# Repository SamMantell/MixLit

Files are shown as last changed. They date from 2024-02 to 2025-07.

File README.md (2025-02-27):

# MixLit - Work in Progress
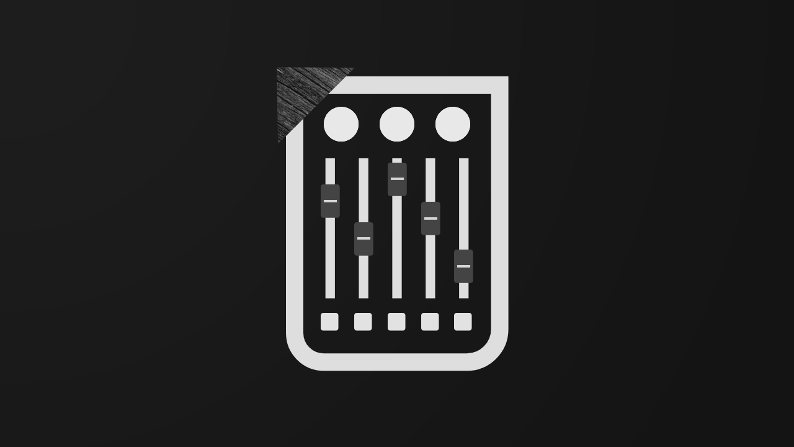
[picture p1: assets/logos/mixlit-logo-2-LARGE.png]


The MixLit is a small sound desk that can control app volumes on a Windows PC. It uses an arduino nano as the controller and talks to our software over USB serial.

The case can be 3D printed and both STEP and STL files are provided

The PCB was designed in KiCAD and we used PCB Way to get them manafactured

Software is a Flutter application.

This repo contains firmware, software and hardware.

# Images
Image of the device:
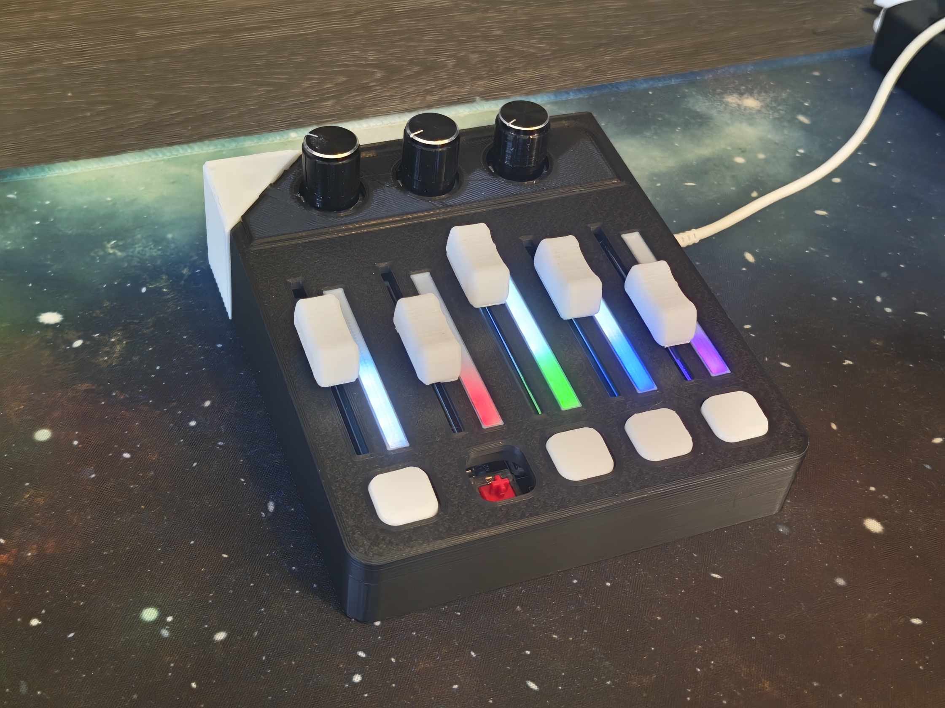
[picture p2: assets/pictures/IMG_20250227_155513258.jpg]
Image of the MixLit

PCB:
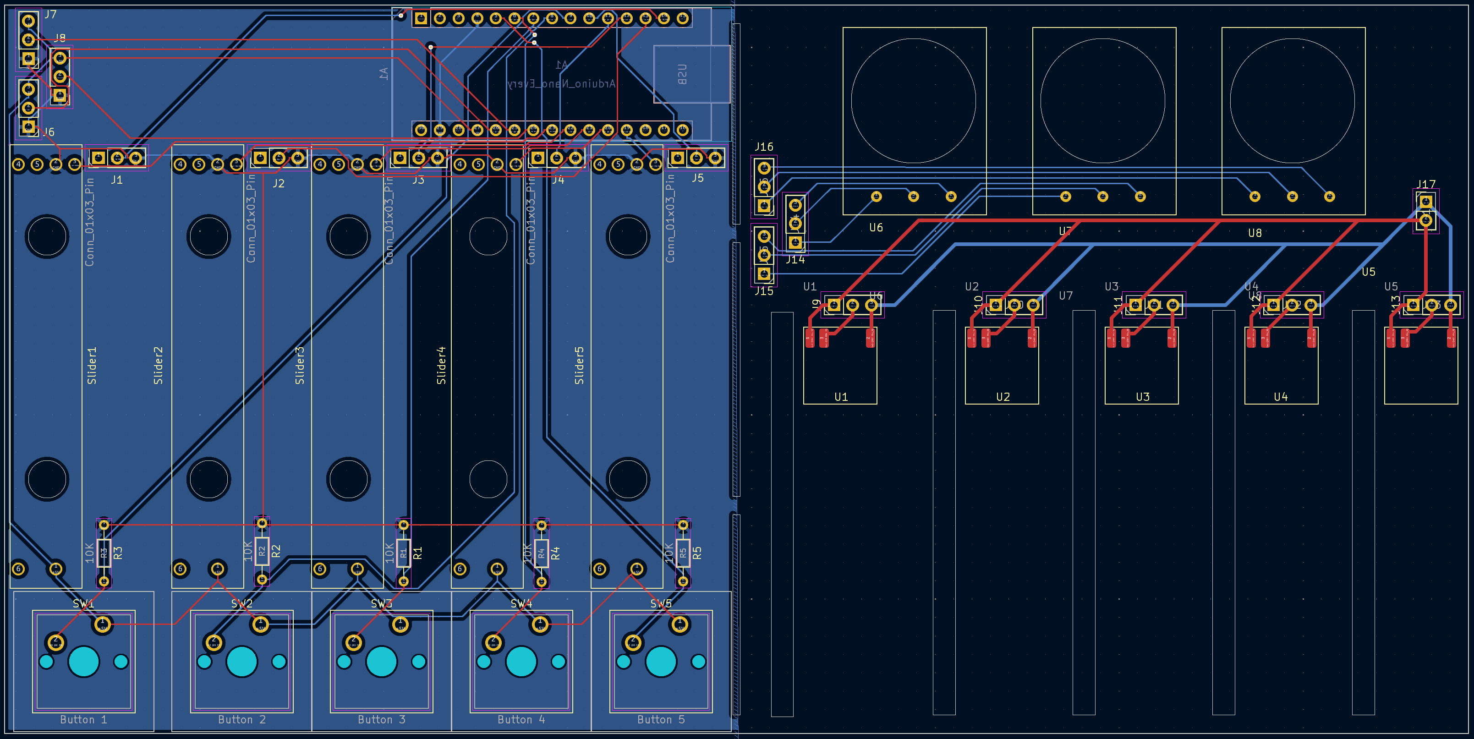
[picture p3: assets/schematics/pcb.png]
Image of the PCB Diagram

Software:
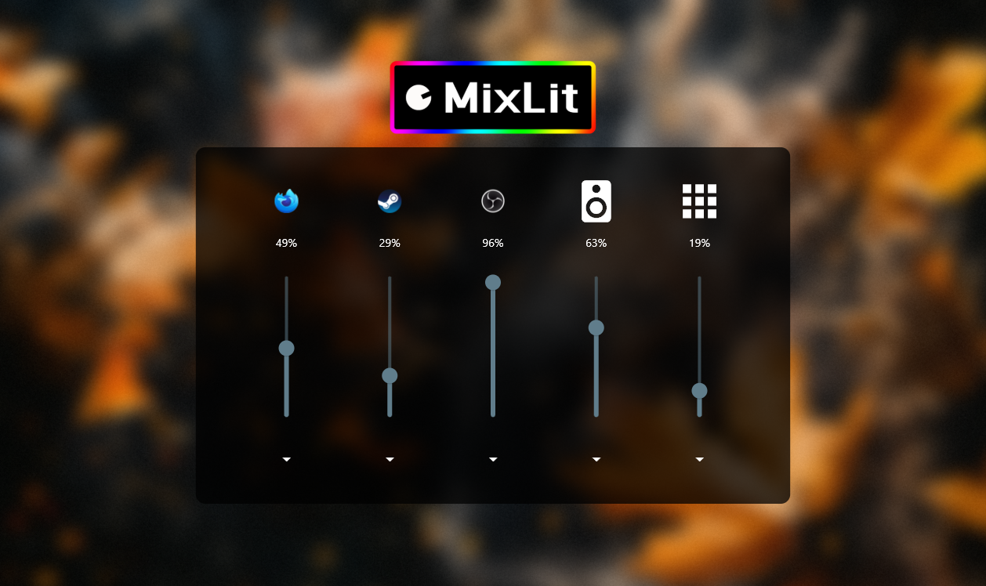
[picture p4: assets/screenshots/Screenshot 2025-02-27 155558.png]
Screenshot of the software


# 📦 Hardware
**» Order the Hardware we used from the links below.**

💡 WS2812B - LIGHTING - https://www.amazon.co.uk/dp/B0CF57NMHN

🎚️ 10K Ohm Slide Potentiometer - https://www.amazon.co.uk/dp/B07PNDLKQQ?psc=1

🎛️ 10K Ohm Rotation Potentiometer - https://www.amazon.co.uk/dp/B07B64MWRF?psc=1

🎮 Arduino Nano - https://www.amazon.co.uk/dp/B0CJHMZZWS

#

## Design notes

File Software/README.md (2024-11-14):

# mixlit

A new Flutter project.

## Getting Started

This project is a starting point for a Flutter application.

A few resources to get you started if this is your first Flutter project:

- [Lab: Write your first Flutter app](https://docs.flutter.dev/get-started/codelab)
- [Cookbook: Useful Flutter samples](https://docs.flutter.dev/cookbook)

For help getting started with Flutter development, view the
[online documentation](https://docs.flutter.dev/), which offers tutorials,
samples, guidance on mobile development, and a full API reference.

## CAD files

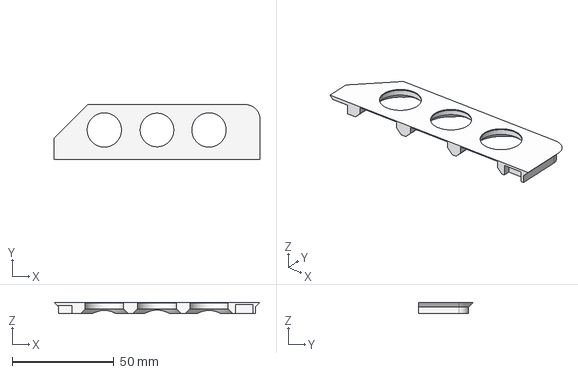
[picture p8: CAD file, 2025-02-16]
Hardware/Case/V2/STEP/Full PCB - Spin Dial Cover.step
101.3 x 26.9 x 5.50 mm

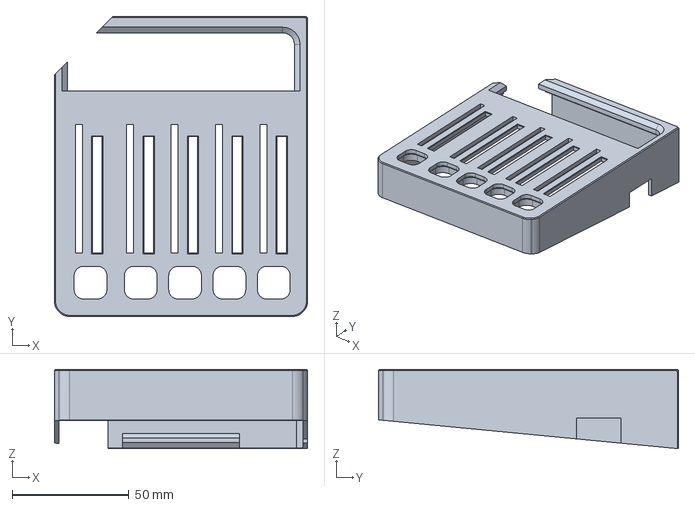
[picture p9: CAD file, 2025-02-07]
Hardware/Case/V2/STEP/Case - Case Main.step
108.5 x 128.5 x 34.0 mm

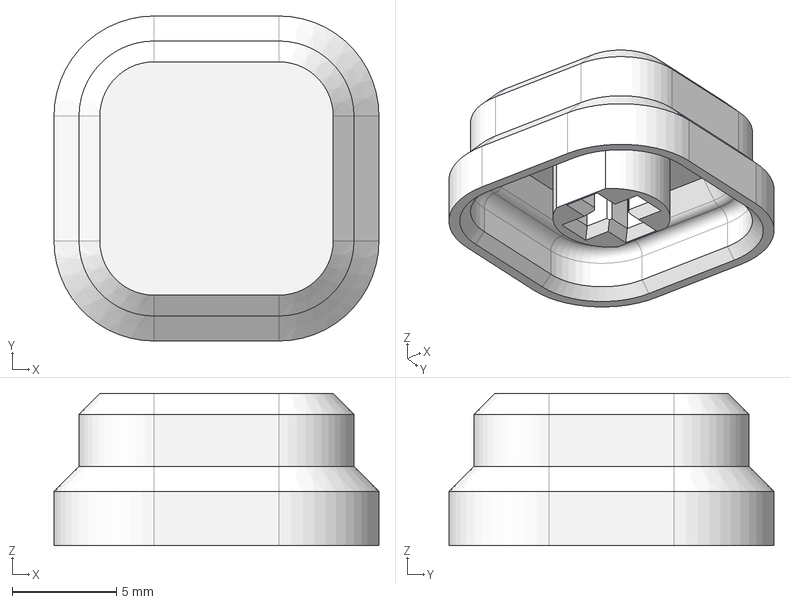
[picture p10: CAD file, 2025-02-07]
Hardware/Case/V2/STEP/Case - Buttons x5.step
15.6 x 15.6 x 7.30 mm

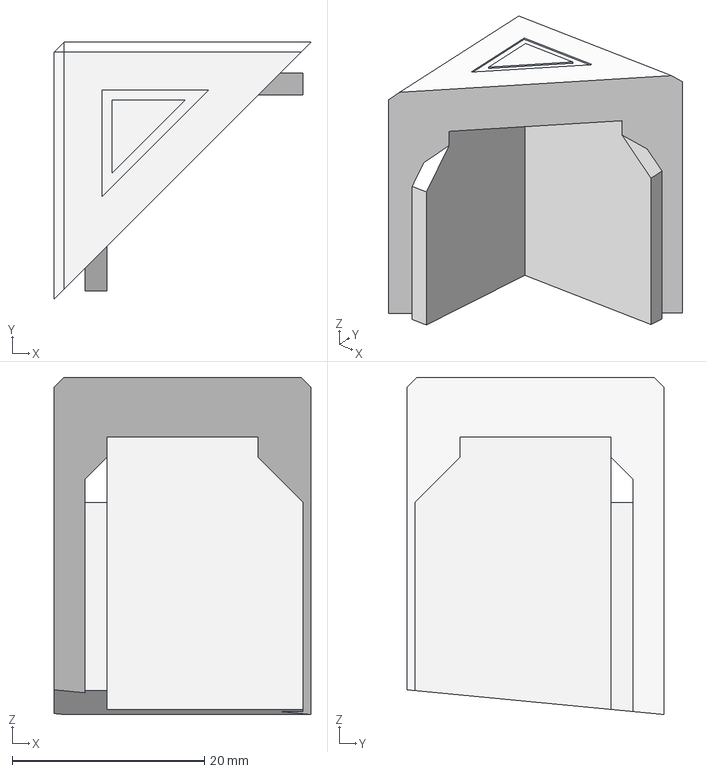
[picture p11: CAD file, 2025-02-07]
Hardware/Case/V2/STEP/Case - Case Corner.step
26.7 x 26.7 x 35.1 mm

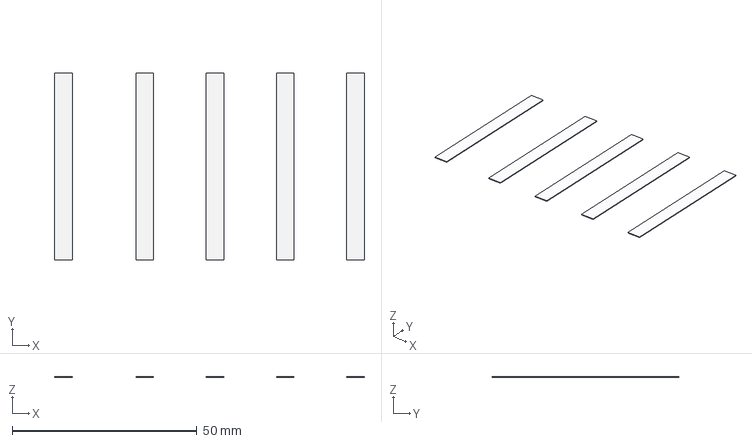
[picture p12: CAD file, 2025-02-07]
Hardware/Case/V2/STEP/Case - LED Diffusers.step
83.8 x 50.5 x 0.24 mm

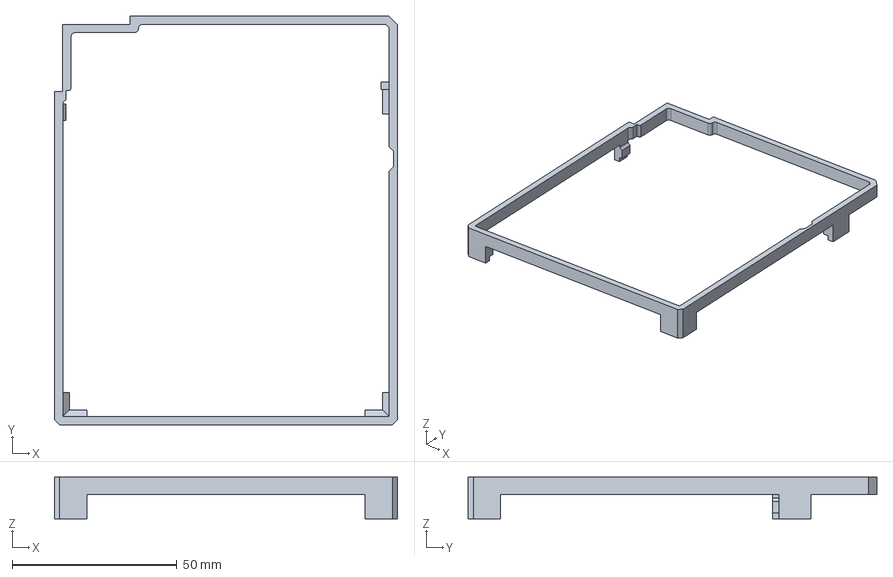
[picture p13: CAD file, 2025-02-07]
Hardware/Case/V2/STEP/Case - Case Middle.step
104.1 x 124.1 x 12.6 mm

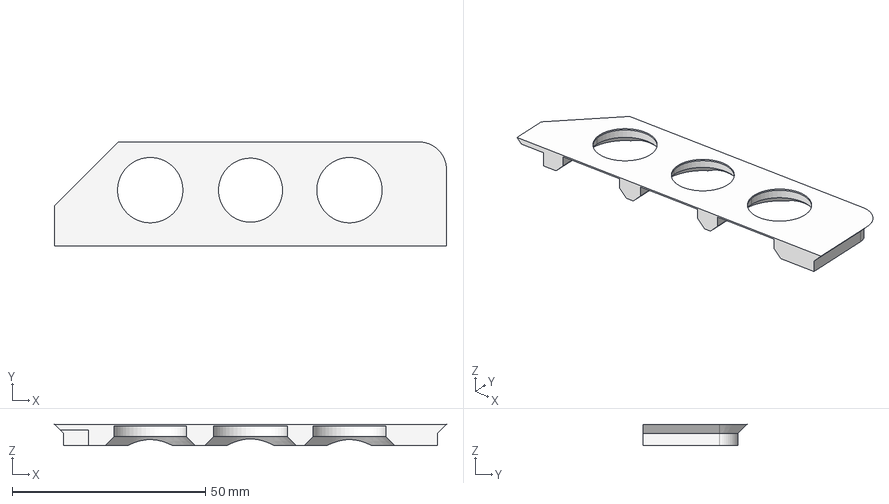
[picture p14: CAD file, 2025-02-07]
Hardware/Case/V2/STEP/Case - Spin Dial Cover.step
101.3 x 26.9 x 5.50 mm

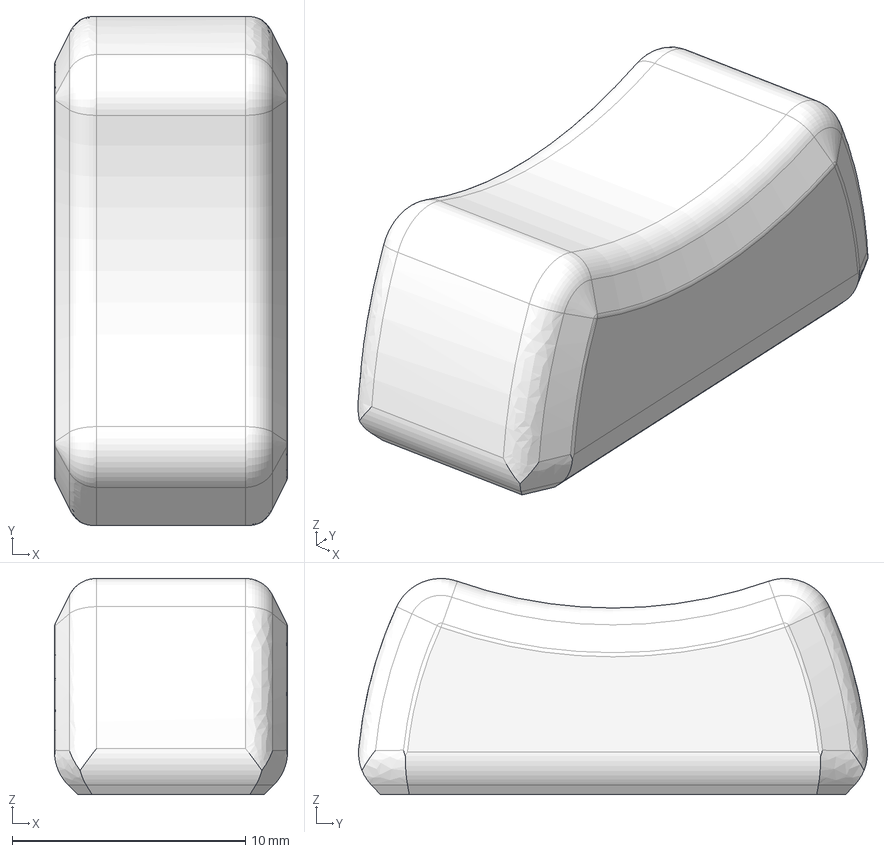
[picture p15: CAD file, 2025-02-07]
Hardware/Case/V2/STEP/Case - Fader Caps x5.step
10.0 x 21.8 x 9.27 mm

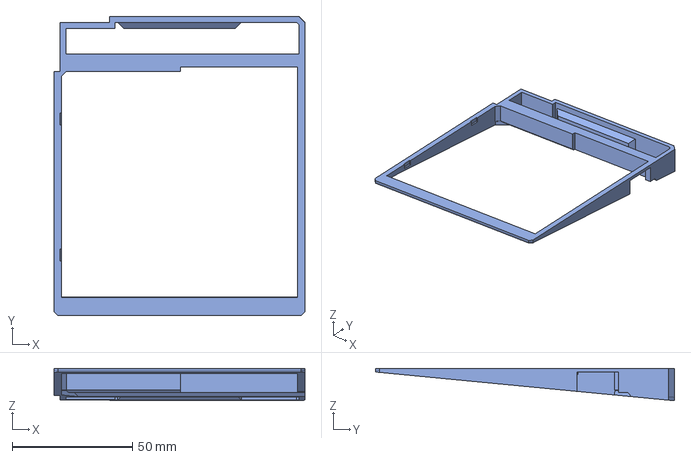
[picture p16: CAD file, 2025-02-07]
Hardware/Case/V2/STEP/Case - Case Bottom.step
104.1 x 124.1 x 13.5 mm

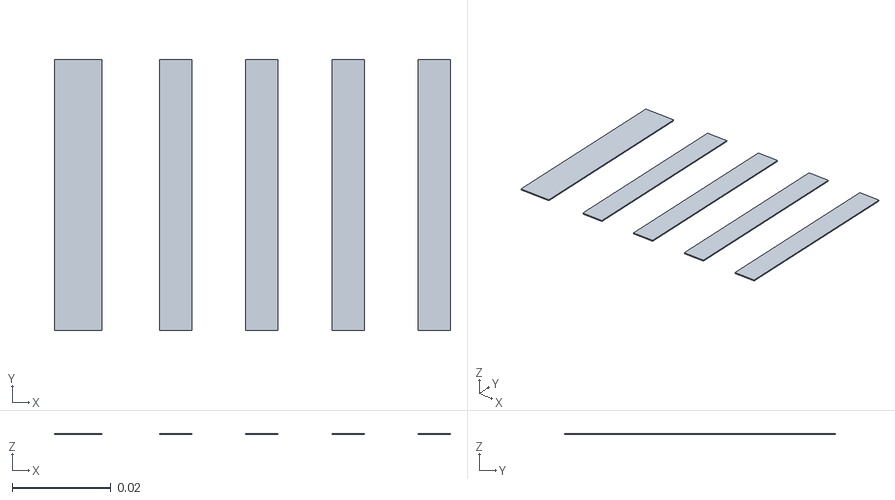
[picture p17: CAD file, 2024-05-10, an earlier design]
Hardware/Case/V1/STLs/Fader Diffusers.stl
0.0804 x 0.0551 x 0.0003

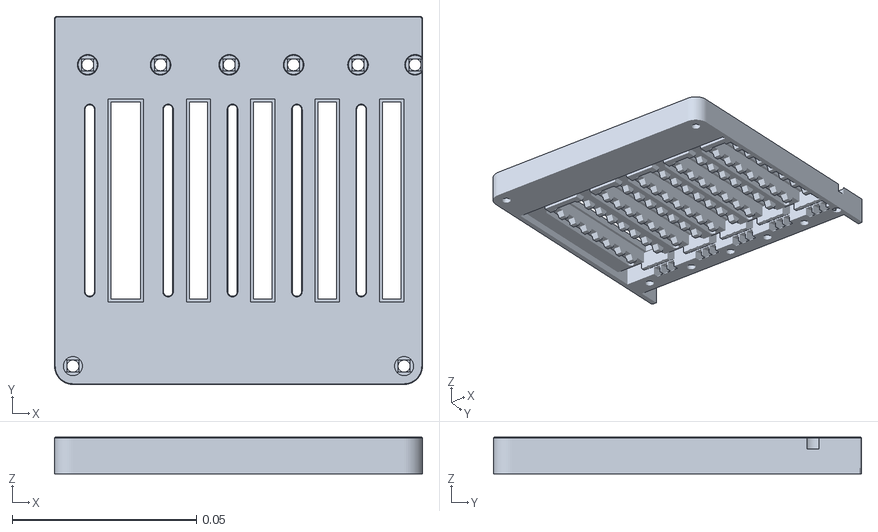
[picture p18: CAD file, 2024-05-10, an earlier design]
Hardware/Case/V1/STLs/Top Piece.stl
0.1 x 0.1 x 0.01

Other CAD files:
Hardware/Case/V1/Drafts/blender file.blend

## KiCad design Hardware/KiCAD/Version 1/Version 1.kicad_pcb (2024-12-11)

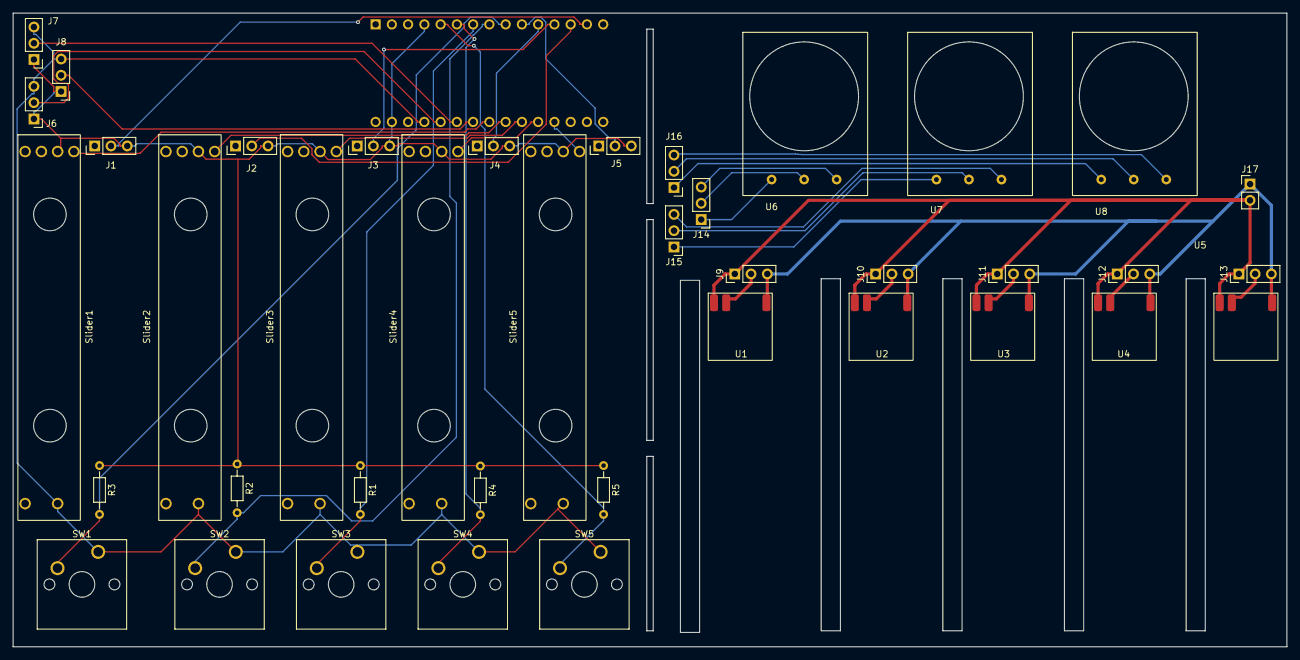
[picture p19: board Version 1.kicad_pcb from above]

Board: 2 copper layers, 199.0 x 99.0 mm, 41 parts (1 on the bottom side), 36 nets.

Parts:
A1: Arduino_Nano_Every; Arduino_Nano
J1, J2, J3, J4, J5, J6, J7, J8, J9, J10, J11, J12, J13, J14, J15, J16: Conn_01x03_Pin; PinHeader_1x03_P2.54mm_Vertical
J17: Conn_01x02_Pin; PinHeader_1x02_P2.54mm_Vertical
R1, R2, R3, R4, R5: 10K; R_Axial_DIN0204_L3.6mm_D1.6mm_P7.62mm_Horizontal
SW1: Button 1; SW_Cherry_MX_1.00u_PCB
SW2: Button 2; SW_Cherry_MX_1.00u_PCB
SW3: Button 3; SW_Cherry_MX_1.00u_PCB
SW4: Button 4; SW_Cherry_MX_1.00u_PCB
SW5: Button 5; SW_Cherry_MX_1.00u_PCB
Slider1, Slider2, Slider3, Slider4, Slider5: Custom Slide Potentiometer Double Linear 10K
U1, U2, U3, U4, U5: Custom LED Strip
U6, U7, U8: Custom Spin Potentiometer

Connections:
+5V: A1.27 (+5V), J6.3, J7.3, J8.3, SW1.1, SW2.1, SW3.1, SW4.1, SW5.1, Slider1.1 (+5V), Slider2.1 (+5V), Slider3.1 (+5V), Slider4.1 (+5V), Slider5.1 (+5V)
GND: A1.4 (GND), A1.29 (GND), J1.3, J2.3, J3.3, J4.3, J5.3, J6.1, J7.1, J8.1, R1.1, R2.1, R3.1, R4.1, R5.1, Slider1.2 (GND), Slider2.2 (GND), Slider3.2 (GND), Slider4.2 (GND), Slider5.2 (GND)
unnamed: A1.19 (A0), Slider5.3 (Data)
unnamed: A1.20 (A1), Slider4.3 (Data)
unnamed: A1.21 (A2), Slider3.3 (Data)
unnamed: A1.22 (A3), Slider2.3 (Data)
unnamed: A1.25 (A6), J7.2
unnamed: A1.26 (A7), J6.2
unnamed: A1.5 (D2), R5.2, SW5.2
unnamed: A1.6 (D3), R4.2, SW4.2
unnamed: A1.7 (D4), R1.2, SW3.2
unnamed: A1.8 (D5), R2.2, SW2.2
unnamed: A1.9 (D6), R3.2, SW1.2
unnamed: A1.10 (D7), J5.2
unnamed: A1.11 (D8), J4.2
unnamed: A1.12 (D9), J3.2
unnamed: A1.13 (D10), J2.2
unnamed: A1.14 (MOSI), J1.2
unnamed: A1.24 (SCL/A5), J8.2
unnamed: A1.23 (SDA/A4), Slider1.3 (Data)
unnamed: J9.2, U1.3 (Data)
unnamed: J9.1, J10.1, J11.1, J12.1, J13.1, J17.2, U1.1 (+5V), U2.1 (+5V), U3.1 (+5V), U4.1 (+5V), U5.1 (+5V)
unnamed: J10.2, U2.3 (Data)
unnamed: J9.3, J10.3, J11.3, J12.3, J13.3, J17.1, U1.2 (GND), U2.2 (GND), U3.2 (GND), U4.2 (GND), U5.2 (GND)
unnamed: J11.2, U3.3 (Data)
unnamed: J12.2, U4.3 (Data)
unnamed: J13.2, U5.3 (Data)
unnamed: J14.1, U6.1 (+5V)
unnamed: J14.2, U6.3 (Data)
unnamed: J14.3, U6.2 (GND)
unnamed: J15.1, U7.1 (+5V)
unnamed: J15.2, U7.3 (Data)
unnamed: J15.3, U7.2 (GND)
unnamed: J16.1, U8.1 (+5V)
unnamed: J16.2, U8.3 (Data)
unnamed: J16.3, U8.2 (GND)

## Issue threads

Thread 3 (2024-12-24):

⚠️ App takes forever to discover device + freezes upon discovery momentarily

Goddeh1, 2024-12-24:
Fix port iteration loop to make it asynchronous + implement config saving COM port to make booting up app after first time launch faster (maybe make a setup sequence in the app for first-time launch??)

Closed 2025-06-30.

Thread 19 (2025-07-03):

Bug: everything muted on app launch

Goddeh1, 2025-07-03:
When app starts, no apps should have their volume changed until one of the sliders is adjusted either via device or on UI drag - **this will maintain current app volumes after PC reboot**

Closed 2025-07-07.

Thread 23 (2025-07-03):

Bug: mute buttons no worky

Goddeh1, 2025-07-03:
what the title said

Closed 2025-07-07.

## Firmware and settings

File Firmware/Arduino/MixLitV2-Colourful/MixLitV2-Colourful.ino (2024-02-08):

/*

MixLit Firmware V2

For Arduino

Authors: Sam Mantell, Goddeh
GitHub: @SamMantell, @Goddeh1

*/

#include <FastLED.h>
#include <MIDIUSB.h>

#ifdef __AVR__
#endif

#define NUM_OF_LED_STRIPS 5
#define NUM_OF_LEDS_PER_STRIP 8

const int NumOfSliders = 5;
char SliderIDs[NumOfSliders] = {'A', 'A', 'A', 'A', 'A'};
const int Sliders[NumOfSliders] = {A1, A2, A3, A4, A5};
int prevSliderState[NumOfSliders];
int SliderState[NumOfSliders];

long currentMillis;
long lastMillis;

int loops = 0;

int colorIndexOffset;

CRGB leds[NUM_OF_LED_STRIPS][NUM_OF_LEDS_PER_STRIP];

CRGBPalette16 All_ColorPallete[5] = 
{
  CRGBPalette16   (
                    0xFFFFFF, 0xFFFFFF, 0xFFFFFF,  0xFFFFFF, 0xFFFFFF, 0xFF0000, 0xFF0000,  0xFF0000,
                    0xFFFFFF, 0xFFFFFF, 0xFFFFFF,  0xFFFFFF, 0xFFFFFF, 0xFFFFFF, 0xFFFFFF,  0xFFFFFF
                  ),
  CRGBPalette16   (
                    0xFFFFFF, 0xFFFFFF, 0xFFFFFF,  0xFFFFFF, 0xFFFFFF, 0xFF0000, 0xFF0000,  0xFF0000,
                    0xFFFFFF, 0xFFFFFF, 0xFFFFFF,  0xFFFFFF, 0xFFFFFF, 0xFFFFFF, 0xFFFFFF,  0xFFFFFF
                  ),
  CRGBPalette16   (
                    0xFFFFFF, 0xFFFFFF, 0xFFFFFF,  0xFFFFFF, 0xFFFFFF, 0x00FF00, 0x00FF00,  0x00FF00,
                    0xFFFFFF, 0xFFFFFF, 0xFFFFFF,  0xFFFFFF, 0xFFFFFF, 0xFFFFFF, 0xFFFFFF,  0xFFFFFF
                  ),
  CRGBPalette16   (
                    0xFFFFFF, 0xFFFFFF, 0xFFFFFF,  0xFFFFFF, 0xFFFFFF, 0x0000FF, 0x0000FF,  0x0000FF,
                    0xFFFFFF, 0xFFFFFF, 0xFFFFFF,  0xFFFFFF, 0xFFFFFF, 0xFFFFFF, 0xFFFFFF,  0xFFFFFF
                  ),
  CRGBPalette16   (
                    0xFFFFFF, 0xFFFFFF, 0xFFFFFF,  0xFFFFFF, 0xFFFFFF, 0xFF00FF, 0xFF00FF,  0xFF00FF,
                    0xFFFFFF, 0xFFFFFF, 0xFFFFFF,  0xFFFFFF, 0xFFFFFF, 0xFFFFFF, 0xFFFFFF,  0xFFFFFF
                  )
};

uint8_t ColorIndex;
uint8_t OtherColorIndex;

void setLEDs(int iCurrentValue, int ledStrip)
{
  colorIndexOffset++;

  uint8_t iNumOfLedsOn = iCurrentValue >> 7;
  uint8_t iFinalLedBrightness = (iCurrentValue % 128) << 1;

  for (int i = 0; i < 8; i++)
  {
    ColorIndex = 16*i + colorIndexOffset;

    if (i == (7 - iNumOfLedsOn))        leds[ledStrip][i] = ColorFromPalette( All_ColorPallete[ledStrip], ColorIndex, iFinalLedBrightness);
  
    else if (i > (7 - iNumOfLedsOn))    leds[ledStrip][i] = ColorFromPalette( All_ColorPallete[ledStrip], ColorIndex, 255);
      
    else                                leds[ledStrip][i] = ColorFromPalette( All_ColorPallete[ledStrip], ColorIndex, 0);
  }

  FastLED.show();
}

void controlChange(byte channel, byte control, byte value) {
  midiEventPacket_t event = {0x0B, 0xB0 | channel, control, value};
  MidiUSB.sendMIDI(event);
}


void setup()
{

  /*

  while (!Serial) {
    delay(10);
  }

  */

  //Wired the LEDs wrong should be 7, 6, 5, 4, 3
  FastLED.addLeds<WS2812, 7, GRB>(leds[0], NUM_OF_LEDS_PER_STRIP);
  FastLED.addLeds<WS2812, 5, GRB>(leds[1], NUM_OF_LEDS_PER_STRIP);
  FastLED.addLeds<WS2812, 6, GRB>(leds[2], NUM_OF_LEDS_PER_STRIP);
  FastLED.addLeds<WS2812, 4, GRB>(leds[3], NUM_OF_LEDS_PER_STRIP);
  FastLED.addLeds<WS2812, 3, GRB>(leds[4], NUM_OF_LEDS_PER_STRIP);

  FastLED.setBrightness(32);
}

void loop()
{ 
  loops++;

  String builtString = String("");

  for (int i = 0; i < NumOfSliders; i++)
  {
    SliderState[i] = analogRead(Sliders[i]);

    setLEDs(SliderState[i], i);

    if (abs(SliderState[i] - prevSliderState[i]) > 2)
    {
      prevSliderState[i] = SliderState[i];

      builtString += String(SliderIDs[i]) + String(i + 1) + "|" + String(SliderState[i]);

      if (i != NumOfSliders - 1)
      {
        builtString += String("|");
      }

      controlChange(1, i, (SliderState[i] >> 3));
      MidiUSB.flush();
    }
  }

  /*
  long currentMillis = millis() - lastMillis;
  if (loops == 100)
  {
    lastMillis += currentMillis;
    loops = 0;
    Serial.println(currentMillis);
  }
  */
}

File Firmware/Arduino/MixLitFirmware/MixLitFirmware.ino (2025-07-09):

/*
MixLit Firmware V2

For Arduino Nano

Authors: Sam Mantell, Goddeh
GitHub: @SamMantell, @Goddeh1

This program is the firmware for the MixLit, it is responsible for taking slider OUTPUTs, sending them to a PC over serial.

Example of changing a slider colour pallete
This would change slider 1 to be a red to yellow gradient with no animation
10FFAA00FF9B00FF8C00FF7B00FF6900FF5400FF3A00FF0000

*/

#include "definitions.h"
#include "mixlit.hpp"

mixlit mixlit;



void setup()
{
  mixlit.initialize();

  mixlit.awaitConnection();
}

void loop()
{
  mixlit.serialHandler();

  mixlit.readStates();

  mixlit.denoiseAndBuildString();

  if (mixlit.stringToSendToSoftware != "")
  {
    Serial.println(mixlit.stringToSendToSoftware);
  }

  FastLED.show();
}

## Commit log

2023-08-10 Working LEDS!!!
2023-08-11 quick spring cleaning
2023-08-11 Optimised LEDs
2023-08-14 Close button
2023-08-15 might've screwed this optimistic experiment up but hopefully its cool
2024-01-05 MixLit V2 Added
    Added new library for the LEDs, now stored in a 2D array, Serial output optimised, some more general optimisations.
2024-01-08 Add Colours to LEDs
    Changed the `setLEDs()` function to make brightness easier and allows for use of colour pallets. Need to create custom colour pallets still.
2024-01-11 Implementation of 2 ColorPalettes
    in theory this should add a colour palette for the main slider and one for the others allowing for potential individual addressment of the LEDs over software, wrote this on a coach, code not varified, may not work use previous commit if it doesnt work (one colour palette for all sliders)
    [MixLitV2-Colourful.ino]
2024-01-12 Fixed code from yesterday
    Yeah that code didn't work, hopefully this should, actually verified this one and it should work, can't actually test it, also its not optimised at all atm.
    [MixLitV2-Colourful.ino]
2024-01-25 Individually Addressable
    Made it possible to address each led individually with use of 2 arrays, one to control the main slider and the other to control the other 4. Fully Working!
2024-01-27 Remove Serial Communication
    (not using it for now and Arduino will wait for a connection in current config so removed.)
2024-02-07 Update To New Palettes
    No longer CONST!
    [MixLitV2-Colourful.ino]
2024-02-08 Update LED type
2024-02-12 Fix no `FastLED.show();` lol
    [MixLitFirmware.ino]
2024-05-10 Add first STLs
    [Fader Diffusers.stl, Top Piece.stl]
2024-11-14 decrease chance of noise
    [MixLitFirmware.ino]
2024-11-15 never back down never what 🗣️
2024-12-04 add blender referance
    [blender file.blend]
2024-12-04 pcb start
    [Version 1.kicad_pcb, Version 1.kicad_sch]
2024-12-05 some more pcbing
2024-12-06 pcb progress
    [Version 1.kicad_pcb, Version 1.kicad_sch]
2024-12-09 some more KiCAD Stuff
    [Version 1.kicad_pcb, Version 1.kicad_sch]
2024-12-11 more kicad stuff
    [Part 2.kicad_pcb, Part 2.kicad_sch, Version 1.kicad_pcb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]
2024-12-11 ready to order maybe
    [Version 1.kicad_pcb, Version 1.kicad_sch]
2024-12-11 to be ordererd
    [Version 1.kicad_pcb]
2024-12-22 Fully working except buttons
2024-12-22 🗣️🔥init 🍵🫖
2024-12-22 🔘🔳 button support maybe
2024-12-23 ✨feat: easily callable dialog for warning messages 🛠️fix: hang on failure of device detection/com-port-open (works with/without device connection now 🎉)
    [MixLitFirmware.ino]
2024-12-23 ✨feat: device connection / disconnection listeners + toast notification
2024-12-24 🛠️fix: device connect / disconnection listener
2024-12-24 fix leds going to zero
    [MixLitFirmware.ino]
2024-12-24 ✨feat: mixlit device establishment via COM port call/response scanning ⚠️issues: non-immediate connection, last com port not stored, takes ages to find device, values aren't restored from device on i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
    [MixLitFirmware.ino]
2024-12-24 🔥opt: sped up device recognition process
2024-12-24 🛠️fix: device + app volumes can now co-exist
2024-12-24 🛠️fix: weird ass muting bug
2024-12-28 🛠️fix: device scanning & detection
    [MixLitFirmware.ino]
2025-02-07 create v2
    [Fader Diffusers.stl, Top Piece.stl, blender file.blend]
2025-02-07 add case v2
    [Case - Buttons x5.step, Case - Case Bottom.step, Case - Case Corner.step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]
2025-02-16 add spin dial cover
    [Full PCB - Spin Dial Cover.step]
2025-02-23 🛠️fix: basically everything
2025-02-23 ✨ firmware now sends data after connection
    committing firmware to software
2025-02-27 ✨ add loading animation
2025-02-27 🔨Optimisations
2025-05-09 🛠️ load last saved
2025-05-09 🛠️ Delay fix (fixes laggy result in software) - 50ms -> 10ms
    [MixLitFirmware.ino]
2025-05-09 🛠️ Windows volume lags when adjusting too often
2025-05-09 🛠️ Firmware: Reduced noise 🛠️ Prevented app being constantly assigned when volume adjustments are being made
    [MixLitFirmware.ino]
2025-05-10 ✨ Mute buttons
2025-05-10 🛠️ Mute buttons more responsive
2025-05-10 🧶Refactor: organised assets
2025-05-10 ✨ Basic UI Redesign
2025-05-10 ✨ feat: Saving to config for state restoration 🚢 prgrs: Device LED control from software 🧹 chore: updated logo and theme
2025-05-10 🛠️ Fix: inconsistent design, consistent font, better text clarity/translations
2025-05-10 🔧 tweak: updated app icon
2025-05-10 🛠️ fix: used local directory of application for config instead of documents 🧶ref: changed mixlit.yml to data.yml
2025-05-10 ✨ feat: (Auto) Updater ✨ feat: installer executable using inno 📂 file: added icons, and other assets required for this release
2025-05-10 🧹chore: organise graphic assets
2025-05-10 ✨ feat: Minimise to system tray
2025-05-10 🧹chore: versioning oopsie lol
2025-05-15 🧶 Refactor: finals/consts added where necessary
2025-05-15 ✨ feat: rate limiting for performance, caching 🧶 refactor: icon colour extraction, only using state when necessary 🔧 tweak: edited main.cpp for window size & title 🛠️ fix: firmware type errors
    [MixLitFirmware.ino, main.cpp]
2025-05-15 🗣️init
2025-05-16 ✨feat: better disconnection handling (no keepalive needed) 🛠️fix: prevented system apps (explorer.exe) without readable file path from causing slider assignment menu breaking ❌rm: temporarily removed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
2025-05-25 🔧updated baud rate to match firmware
2025-06-08 add buttons to firmware
2025-06-13 ✨ Launch (minimised) on startup ✨ Draggable window ✨ Slight app assigner menu UI update 🔧 Already assigned apps are not listed in app assigner 🛠️ Fixed device volume being muted on start
2025-07-03 🛠️ fix #15: config now stored in appdata
2025-07-03 🛠️ fix: connection status indicator overflow (when disconnected)
2025-07-03 make only 2 dials for starts of dial integration (left one broke lol)
    [mixlit.hpp]
2025-07-03 ✨feat: dynamic audio session management & app caching (fixes #14)
2025-07-03 🛠️fix #18: show window on manual open (and minimise on startup)
2025-07-03 LED updates are now instant
2025-07-07 ✨feat #20: dial support ✨feat #22: settings menu added 🛠️fix #23: mute buttons work again 🛠️fix #19: assigned apps no longer muted on launch
2025-07-07 🧶update version
